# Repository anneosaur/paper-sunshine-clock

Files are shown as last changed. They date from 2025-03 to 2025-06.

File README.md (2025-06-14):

# paper sunshine clock


This project is a clock that tells time in a unique way. The face of the display looks like the sun with 12 rays representing 12 o’clock to 11 o’clock, going clockwise, which turn from black to yellow as the day progresses. Each ray is divided up into half hour segments, so the clock is able to tell you the current half hour. For example in the photo above, the clock is reading between 9 o’clock and 9:30. The display is made out of paper and uses thermochromic paint that changes color with heat. There is a thin circuit board behind the paper which provides the warmth to activate the thermochromic paint, changing the color of the rays. The clock also has Sparkle Mode, which will turn on a random ray every 10 seconds. It provides an entertaining show as the rays turn on and fade away (see [Videos](#Videos) below). The enclosure is 3D printed.

https://github.com/user-attachments/assets/e0f1c668-d030-4747-b99e-f9c4dc16aae8

---
### Reading the clock
The clock has 12 rays, representing 12 hours from 12 o'clock to 11 o'clock. Each ray is divided up into half hour segments. As each half hour of the day passes, the corresponding segment will turn from black to yellow. The clock face is fully yellow between 11:30-11:59. At 12:00, it'll reset. 

face_diagram

---
### How it works
The clock works by using thermochromic paint screen printed onto a piece of Japanese awagami paper. Behind that, is a flex PCB with large resistors mounted on the back. These resistors can be selectively turned on, warming up the paper and activating the thermochromic paint. 
Each ray on the PCB is a copper pour used to spread and hold heat from the resistors. It was designed using Python and an SVG drawing library, and converted into a KiCad footprint.

display_front_sm
display_back_sm

The control board is driven by an Atmega328PB and uses a DS3231MZ RTC for accurate time keeping. A coin cell battery is used to keep track of time even when the clock is unpowered. The time is initially set when programming the clock, and can be changed in +/- 30 minute increments using the two buttons on the back.

control_pcb_sm

It uses a multiplexing system which allows the 24 segments to be controlled with 10 connections. The rays of the clock are divided in 3 groups, with 4 rays each. Each group has a top and bottom ground connection connecting the rays (allowing the half hour segments to be individually controlled). The “similar” rays of each group (e.g., the first ray of each group, the second ray of each group, etc) have a shared 5v connection. So for example, to turn on the segment representing the first half hour of 12 o’clock, ground the bottom connection of the first group and apply 5v to the first ray.

display_schematic

For safety (since we’re applying heat to paper here), I used an eFuse to clamp the input voltage at 5v. There are also SMD fuses to prevent against excessive current going through the segments. 

In order to keep the rays at the proper temperature to activate the thermochromic paint (ideally around 90-95 F / 32-35 C), a temperature sensor reads the ambient temperature and will PWM the display to maintain a reasonably consistent temperature. This actually got a bit complicated, since the heat from the display would warm up the back compartment where the control PCB is and influence the temperature sensor. Fortunately, the temperature increases were fairly predicable and could be compensated for. From testing, the clock works well in room temperatures between 65-80 F / 18-27 C.

back_sm
front_side_sm
side_sm

# Videos

[Startup sequence](https://www.youtube.com/watch?v=sf5E_oBU3c0)

[5 minutes of Sparkle Mode in real time](https://www.youtube.com/watch?v=p_eX9BhE4EM)

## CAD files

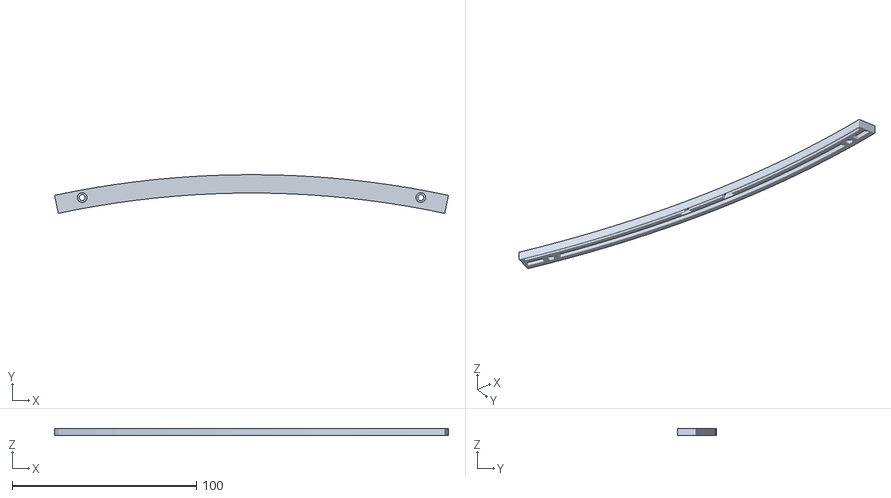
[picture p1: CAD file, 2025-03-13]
enclosure/stls/clock_enclosure_top.stl
214.1 x 21.0 x 4.00

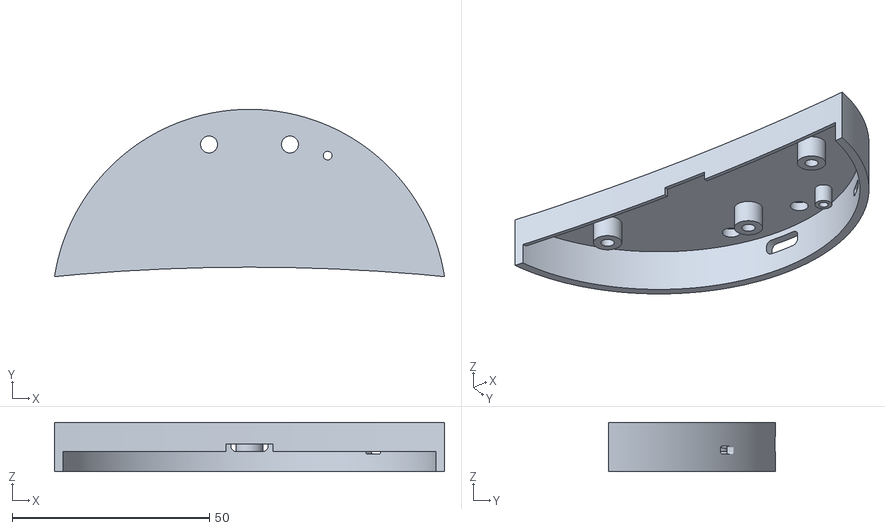
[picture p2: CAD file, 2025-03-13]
enclosure/stls/back_case.stl
98.8 x 42.4 x 12.5

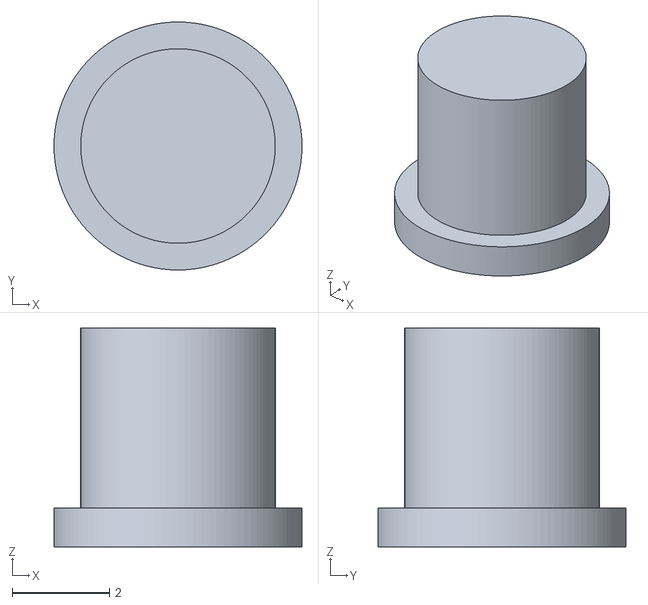
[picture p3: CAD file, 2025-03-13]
enclosure/stls/button.stl
5.10 x 5.10 x 4.50

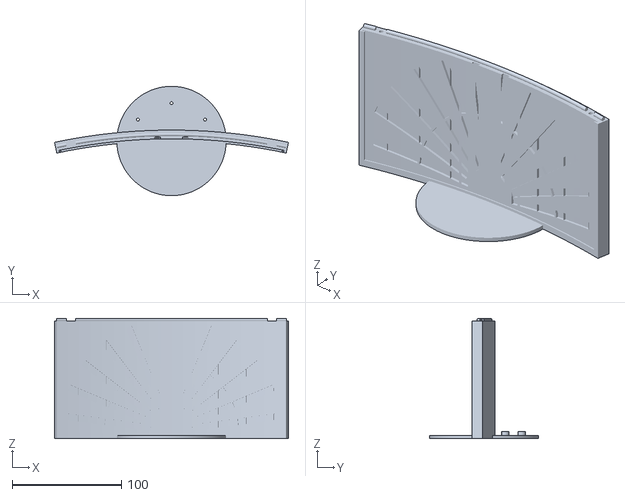
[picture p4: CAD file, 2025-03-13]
enclosure/stls/clock_enclosure.stl
214.1 x 100.0 x 110.2

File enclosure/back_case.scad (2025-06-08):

use <dotSCAD/rounded_square.scad>
include <common.scad>

$fn = 128;

button_diam = 4.2;
button_x = 20.5 / 2;
button_y = pcb_radius - 6.5;
button_thickness = 1;

light_pipe_outer_diam = 4;
light_pipe_inner_diam = 2.1;
light_pipe_coord_x = 19.8;
light_pipe_coord_y = 27.88 + 10.4;
led_height = 1;

module Pcb() {
  translate([0, 0, inner_height - top_standoff_height - pcb_thickness])
    linear_extrude(pcb_thickness)
      difference() {
        circle(pcb_radius);
        translate([0, -main_radius, 0])
        circle(main_radius + thickness + pcb_reduction);
        ScrewHoles(screw_outer_diam);
      }
}

module Inner() {
  difference() {
    linear_extrude(inner_height)
    circle(inner_radius);

    translate([0, 0, inner_height -top_standoff_height ])
    linear_extrude(top_standoff_height)
    translate([0, -main_radius, 0])
    circle(main_radius + thickness + 1);
  }
}

module Outer() {
  linear_extrude(outer_height)
    difference() {
      circle(d = base_diam);
      translate([0, -main_radius, 0])
        circle(main_radius + thickness);
    }
}

module UpperSandoffs() {
  difference() {
  translate([0, 0, inner_height - top_standoff_height])
    linear_extrude(top_standoff_height)
      ScrewHoles(standoff_diam);

  translate([0, 0, inner_height - top_standoff_height])
    linear_extrude(screw_insert_height)
      ScrewHoles(standoff_hole_diam);
  }
}

module LightPipe() {
  difference() {
    translate([light_pipe_coord_x, light_pipe_coord_y, inner_height - top_standoff_height + led_height])
      linear_extrude(top_standoff_height - led_height)
        circle(d=light_pipe_outer_diam);

    translate([light_pipe_coord_x, light_pipe_coord_y, inner_height - top_standoff_height + led_height])
      linear_extrude(top_standoff_height - led_height)
        circle(d=light_pipe_inner_diam);
  }
}

module LightPipeCutout() {
  translate([light_pipe_coord_x, light_pipe_coord_y, 0])
    linear_extrude(outer_height)
      circle(d=light_pipe_inner_diam);
}

module BackCover() {
  difference() {
    Outer();
    Inner();
    CableCutout();
    ButtonCutout();
    UsbCutout();
    LightPipeCutout();
    TempSensorCutout();
  }
  UpperSandoffs();
  LightPipe();
}

module CableCutout() {
  length = 12;
  height = 2;
  translate([-length / 2, 5, inner_height - top_standoff_height])
    cube([length, 10, height]);
}

module ButtonCutout() {
  translate([button_x, button_y, 0])
    linear_extrude(outer_height + 1)
      circle(d = button_diam);

  translate([-button_x, button_y, 0])
    linear_extrude(outer_height + 1)
      circle(d = button_diam);
}

module ButtonStandoff() {
  translate([button_x, button_y, 0])
    linear_extrude(outer_height + 2)
      circle(d = button_diam);

  translate([-button_x, button_y, 0])
    linear_extrude(outer_height + 2)
      circle(d = button_diam);
}

module UsbCutout() {
  usb_w = 3.78;
  usb_h = 9.44;
  translate([0, 52, -usb_w / 2 + inner_height - top_standoff_height + usb_w])
    rotate([90, 0, 0])
      linear_extrude(5)
        rounded_square([usb_h, usb_w], corner_r = 1.5, center = true);
}

module TempSensorCutout() {
  translate([adjacent(49, 45), opposite(49, 45), inner_height - top_standoff_height + pcb_thickness])
  rotate([-49, 90, 0])
  linear_extrude(5)
  rounded_square([2, 5], corner_r=0.5, center=true);
}

//Pcb();
BackCover();

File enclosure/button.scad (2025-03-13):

$fn = 100;

linear_extrude(0.8)
circle(d=5.1);

linear_extrude(4.5)
circle(d=4);

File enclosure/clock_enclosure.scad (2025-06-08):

use <dotSCAD/arc.scad>
use <dotSCAD/util/radians.scad>
use <dotSCAD/util/degrees.scad>
include <common.scad>

use <dotSCAD/bend.scad>

$fn = 128;


// Enclosure
enclosure_display = "W"; // [F:Full, T:Top Only, W:Without top]

module Base() {
  difference() {
    linear_extrude(bottom)
      circle(d = base_diam);
  }
}

module BaseStandoffs() {
  difference() {
    translate([0, 0, bottom])
      linear_extrude(bottom_standoff_height)
        ScrewHoles(standoff_diam);

    BottomScrewHoles();
  }
}

module BottomScrewHoles() {
  linear_extrude(10)
    ScrewHoles(screw_outer_diam);

  linear_extrude(screw_head_height)
    ScrewHoles(screw_head_diam);
}

module Body() {
  linear_extrude(total_height)
    arc(
      radius = main_radius,
      angle = [90 - angle / 2, 90 + angle / 2],
      width = thickness,
      width_mode = "LINE_OUTWARD"
    );
}

module CableCutOut() {
  coutout_height = 5;
  coutout_width = 12;

  translate([-coutout_width / 2, -thickness, bottom])
    cube([coutout_width, thickness*2, coutout_height]);
}

module FrontCutout() {
  translate([0, 0, bottom + margin/2])
    linear_extrude(paper_visable_h)
      arc(
        radius = main_radius,
        angle = [90 - front_cutout_angle / 2, 90 + front_cutout_angle / 2],
        width = paper_setback,
        width_mode = "LINE_OUTWARD"
      );
}

module Paper() {
  translate([0, 0, bottom])
    linear_extrude(paper_h)
      arc(
        radius = paper_radius,
        angle = [90 - paper_angle / 2, 90 + paper_angle / 2],
        width = paper_thickness,
        width_mode = "LINE_OUTWARD"
      );
}

module ResistorCutout() {
    translate([0, -206/radians(angle) +resistor_thickness+paper_setback + paper_thickness, 3])
    rotate([0, 0, 90 - angle/2])
    bend(size = [206, 106, resistor_thickness], angle = angle)
    linear_extrude(2)
    import("clock_face.svg");
}

module ScrewInserts(diam, height, z) {
  translate([0, thickness / 2 + paper_setback, z])
    rotate([0, 0, 10.5])
      translate([0, main_radius, 0])
        linear_extrude(height)
          circle(d = diam);

  translate([0, thickness / 2 + paper_setback, z])
    rotate([0, 0, -10.5])
      translate([0, main_radius, 0])
        linear_extrude(height)
          circle(d = diam);
}

module TopRetainingClip(diam){
    translate([0, -main_radius+ thickness / 2 + paper_setback, total_height-margin+1.2])
    rotate([0, 0, (90 - 20/2)])
    rotate_extrude(angle=20) translate([main_radius,0,0]) circle(d=diam);

    translate([0, -main_radius+ thickness / 2 + paper_setback, total_height-margin+1.2])
    rotate([0, 0, 78]) // 78
    rotate_extrude(angle=1) translate([main_radius,0,0]) circle(d=diam); // 1

    translate([0, -main_radius+ thickness / 2 + paper_setback, total_height-margin+1.2])
    rotate([0, 0, 102]) // 102
    rotate_extrude(angle=-1) translate([main_radius,0,0]) circle(d=diam); // -1
}

module Enclosure() {
    difference() {
      union() {
        translate([0, -main_radius, 0])
          Body();
        Base();
      }
      CableCutOut();

      translate([0, -main_radius, 0])
      union() {
        ScrewInserts(standoff_hole_diam, margin + 4, total_height -margin - 4);
        ScrewInserts(screw_head_diam, screw_head_height, total_height - 1);
      }

      translate([0, -main_radius, 0])
      union() {
        Paper();
        FrontCutout();
      }

      ResistorCutout();
      BottomScrewHoles();
    }

  BaseStandoffs();
}

module EnclosureWithoutTop() {
  cube_w = paper_w + margin * 2;

  difference() {
    Enclosure();
    translate([-cube_w/2, -base_diam / 2, total_height - margin])
      cube([cube_w, base_diam, margin]);
  }
  TopRetainingClip(3);
}

module EnclosureTop() {
  cube_w = paper_w + margin * 2;
  cube_d = base_diam;
  cube_z = total_height - margin;
  difference() {
    Enclosure();
    TopRetainingClip(3.4);

    translate([-cube_w/2, -cube_d/2, 0])
    cube([cube_w, cube_d, cube_z]);  
  }
}

if (enclosure_display == "F") Enclosure();
if (enclosure_display == "T") EnclosureTop();
if (enclosure_display == "W") EnclosureWithoutTop();

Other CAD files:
enclosure/common.scad

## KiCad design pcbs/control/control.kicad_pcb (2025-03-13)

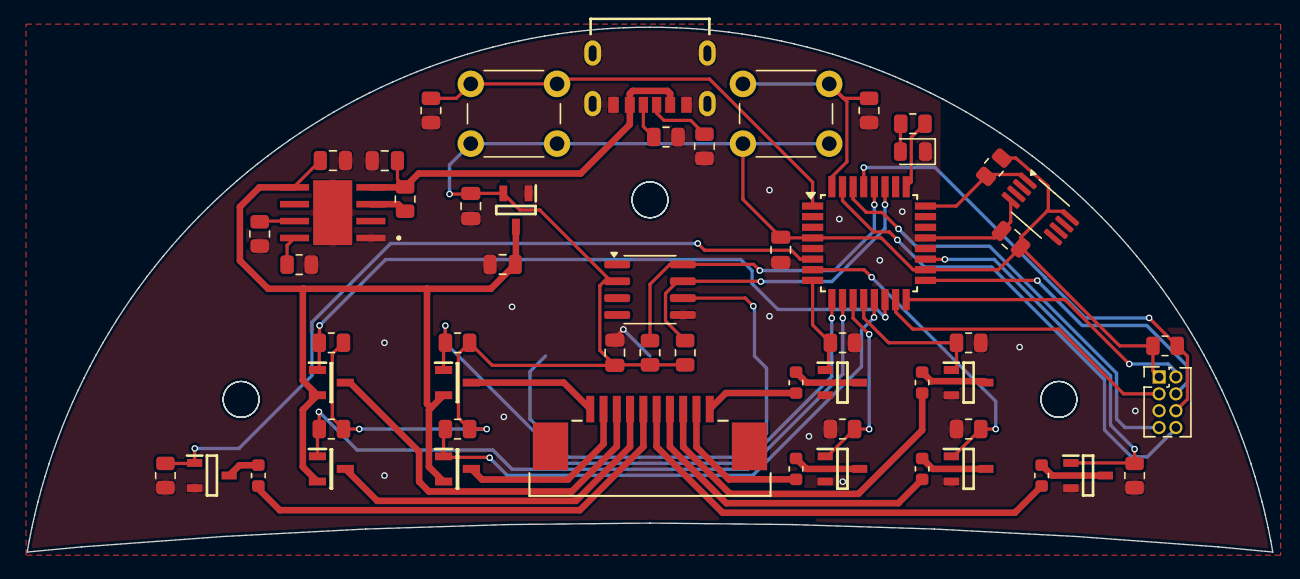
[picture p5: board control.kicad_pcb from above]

Board: 2 copper layers, 93.8 x 39.5 mm, 58 parts (1 on the bottom side), 49 nets.

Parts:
BT1: 3000TR; BAT_3000TR
C1, C6: 1uF; C_0805_2012Metric
C2, C3, C4, C8: 0.1uF; C_0805_2012Metric
C5: 2.2uF; C_0805_2012Metric
D1: LED; LED_0805_2012Metric
D5: AP2210N-3.3TRG1; SOT95P282X145-3N
F1, F2, F3, F4, F5, F6: Fuse; Fuse_0603_1608Metric
J2: USB4125-GF-A-0190; GCT_USB4125-GF-A-0190_REVA2
J3: Conn_01x10_Pin; CON10_SMT-RA_FCC-FPC2
J4: Conn_02x04_Odd_Even; PinHeader_2x04_P1.27mm_Vertical
Q1, Q2, Q3, Q4: SI2393DS-T1-GE3; SOT95P237X112-3N
Q5, Q6, Q7, Q8, Q9, Q10: DMN2020LSN-7; SOT95P285X130-3N
R1, R2, R3, R4, R5, R6, R7, R8, R9, R10, R13, R14, R17: 10k; R_0805_2012Metric
R11, R12, R20: 4.7k; R_0805_2012Metric
R15, R16: 5.1k; R_0805_2012Metric
R18: 60; R_0805_2012Metric
R19: 500; R_0805_2012Metric
R21, R22: 400k; R_0805_2012Metric
Ref**: Val**; control_pcb_outline
SW1: Sparkle; SW_PUSH_6mm
SW2: Time Adj; SW_PUSH_6mm
U1: DS18B20U; MSOP-8_3x3mm_P0.65mm
U2: DS3231MZ; SOIC-8_3.9x4.9mm_P1.27mm
U3: TPS259621DDAT; IC_TPS259621DDAT
U6: ATmega328PB-A; TQFP-32_7x7mm_P0.8mm

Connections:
/3.3v: C2.2, C3.2, C5.2, C8.2, D5.2 (VOUT), J4.1, R1.1, R2.1, R3.1, R4.1, R11.1, R12.1, R17.1, R20.1, SW1.1, SW2.1, U1.8 (V_{DD}), U2.2 (VCC), U6.4 (VCC), U6.18 (AVCC)
/5v: C1.2, C6.2, D5.3 (VIN), Q1.2 (S), Q2.2 (S), Q3.2 (S), Q4.2 (S), U3.5 (OUT)
/ADC1: R20.2, U1.1 (DQ), U6.24 (PC1)
/ADC2: R18.2, U6.25 (PC2)
/ADC6: Q10.1 (G), R10.2, U6.19 (PE2)
/G1B: F2.2, J3.6
/G1T: F1.2, J3.5
/G2B: F4.2, J3.8
/G2T: F3.2, J3.7
/G3B: F5.2, J3.9
/G3T: F6.2, J3.10
/MISO: J4.2, U6.16 (PB4)
/MOSI: J4.3, U6.15 (PB3)
/PIN 2: R13.2, SW2.2, U6.32 (PD2)
/PIN 3: R14.2, SW1.2, U6.1 (PD3)
/PIN 5: Q1.1 (G), R1.2, U6.9 (PD5)
/PIN 6: Q4.1 (G), R4.2, U6.10 (PD6)
/PIN 7: Q7.1 (G), R7.2, U6.11 (PD7)
/PIN 8: Q8.1 (G), R8.2, U6.12 (PB0)
/PIN 9: Q2.1 (G), R2.2, U6.13 (PB1)
/PIN 10: Q3.1 (G), R3.2, U6.14 (PB2)
/PIN 20: Q9.1 (G), R9.2, U6.7 (XTAL1/PB6)
/PIN 21: Q6.1 (G), R6.2, U6.8 (XTAL2/PB7)
/PIN 24: Q5.1 (G), R5.2, U6.6 (PE1)
/RESET: J4.6, R17.2, U6.29 (~RESET/PC6)
/RTC_BAT: BT1.P1, BT1.P2, U2.6 (VBAT)
/RX: J4.7, U6.30 (PD0)
/SCK: J4.4, U6.17 (PB5)
/SCL: R11.2, U2.8 (SCL), U6.28 (PC5)
/SDA: R12.2, U2.7 (SDA), U6.27 (PC4)
/TX: J4.8, U6.31 (PD1)
/V1: J3.1, Q1.3 (D)
/V2: J3.2, Q2.3 (D)
/V3: J3.3, Q3.3 (D)
/V4: J3.4, Q4.3 (D)
/VBUS: C4.2, J2.A9 (VBUS_1), J2.B9 (VBUS_2), R22.1, U3.4 (IN)
GNDD: BT1.N, C1.1, C2.1, C3.1, C4.1, C5.1, C6.1, C8.1, D1.1 (K), D5.1 (GND), J2.A12 (GND_1), J2.B12 (GND_2), J2.S1, J2.S2, J2.S3, J2.S4, J4.5, Q5.2 (S), Q6.2 (S), Q7.2 (S), Q8.2 (S), Q9.2 (S), Q10.2 (S), R5.1, R6.1, R7.1, R8.1, R9.1, R10.1, R13.1, R14.1, R15.1, R16.1, R19.1, R21.2, U1.4 (GND), U2.5 (GND), U3.1 (GND), U3.9 (EXP), U6.5 (GND), U6.21 (GND)
unnamed: D1.2 (A), R18.1
unnamed: J2.A5 (CC1), R15.2
unnamed: J2.B5 (CC2), R16.2
unnamed: F1.1, Q5.3 (D)
unnamed: F6.1, Q6.3 (D)
unnamed: F5.1, Q7.3 (D)
unnamed: F4.1, Q8.3 (D)
unnamed: F3.1, Q9.3 (D)
unnamed: F2.1, Q10.3 (D)
unnamed: R22.2, U3.3 (EN/UVLO)
unnamed: R19.2, U3.7 (ILM)
unnamed: R21.1, U3.8 (OVCSEL)

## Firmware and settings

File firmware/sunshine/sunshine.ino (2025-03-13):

#include <DS3231.h>
#include <DS18B20.h>
#include <avr/wdt.h>

#define VA 5
#define VB 9
#define VC 10
#define VD 6

#define GB1 A6
#define GT1 24

#define GB2 8
#define GT2 20

#define GB3 7
#define GT3 21

#define LED A2

#define TIME_ADJ_BTN 3
#define MODE_ADJ_BTN 2

#define DELAY 1000

#define SPARKLE_RECENT_COUNT 20

#define MODE_CLOCK 0
#define MODE_SPARKLE 1
#define MODE_TIME_SET 2
#define MODE_TIME_RESET 3

DS3231 myRTC;
DS18B20 ds(A1);

int voltageSupply[4] = { VA, VB, VC, VD };

int ground[3][2] = {
  { GB1, GT1 },
  { GB2, GT2 },
  { GB3, GT3 },
};

bool h12Flag;
bool pmFlag;

int lastSegment;

volatile int mode = MODE_CLOCK;
volatile bool modeSwitch = false;

volatile bool incrementTimeTriggered = false;
volatile bool decrementTimeTriggered = false;
unsigned long lastTimeSetTouch = 0;

unsigned long lastTimeResetTouch = 0;
volatile bool timeResetTriggered = false;
int timeResetBtnCount = 0;

unsigned long lastTempUpdate = 0;
float lastTemp;


int sparkleRecent[SPARKLE_RECENT_COUNT] = {};

void setup() {

  wdt_enable(WDTO_8S);
  Wire.begin();

  pinMode(LED, OUTPUT);

  pinMode(VA, OUTPUT);
  pinMode(VB, OUTPUT);
  pinMode(VC, OUTPUT);
  pinMode(VD, OUTPUT);

  pinMode(GB1, OUTPUT);
  pinMode(GT1, OUTPUT);

  pinMode(GB2, OUTPUT);
  pinMode(GT2, OUTPUT);

  pinMode(GB3, OUTPUT);
  pinMode(GT3, OUTPUT);

  pinMode(TIME_ADJ_BTN, INPUT);
  pinMode(MODE_ADJ_BTN, INPUT);

  reset();

  myRTC.setClockMode(true);

  attachInterrupt(digitalPinToInterrupt(TIME_ADJ_BTN), interruptTimeSetMode, RISING);
  attachInterrupt(digitalPinToInterrupt(MODE_ADJ_BTN), interruptSparkleMode, RISING);

  ds.selectNext();

  lastSegment = getSegment();

  digitalWrite(LED, HIGH);
  clockStartup();
  digitalWrite(LED, LOW);
}

void interruptSparkleMode() {
  static unsigned long last_interrupt_time = 0;
  unsigned long interrupt_time = millis();

  if (interrupt_time - last_interrupt_time > 500) {
    if (mode == MODE_CLOCK) {
      mode = MODE_SPARKLE;
      digitalWrite(LED, HIGH);
    } else if (mode == MODE_SPARKLE) {
      mode = MODE_CLOCK;
      modeSwitch = true;
      digitalWrite(LED, LOW);
    } else if (mode == MODE_TIME_SET) {
      incrementTimeTriggered = true;
      lastTimeSetTouch = millis();
    }
  }
  last_interrupt_time = interrupt_time;
}

void interruptTimeSetMode() {
  static unsigned long last_interrupt_time = 0;
  unsigned long interrupt_time = millis();

  if (interrupt_time - last_interrupt_time > 500) {
    if (mode == MODE_CLOCK) {
      digitalWrite(LED, HIGH);
      mode = MODE_TIME_SET;
      modeSwitch = true;
    } else if (mode == MODE_TIME_SET) {
      decrementTimeTriggered = true;
    } else if (mode == MODE_SPARKLE) {
      mode = MODE_TIME_RESET;
      timeResetTriggered = true;
      modeSwitch = true;
    } else if (mode == MODE_TIME_RESET) {
      timeResetTriggered = true;
    }
  }
  last_interrupt_time = interrupt_time;
}

void clockSequence(int holdDelay, int segment, int pwm, bool returnEarly = false) {
  for (int i = 0; i < 4; i++) {
    for (int s = 0; s <= segment; s++) {
      if (int(floor((s % 8) / 2)) == i) {
        turnOn(s, pwm);
        if (returnEarly && segment == s) {
          _delay(holdDelay);
          reset();
          return;
        };
      }
    }
    _delay(holdDelay);
    reset();
  }
}

void clockStartup() {
  int segment = getSegment();
  int startupDelay = getStartupDelay();
  int stopSegment;
  bool returnEarly = false;

  stopSegment = (segment < 7) ? segment : 7;
  if (stopSegment <= 7) returnEarly = true;
  clockSequence(startupDelay, stopSegment, 0, returnEarly);

  if (segment > 7) {
    stopSegment = (segment < 15) ? segment : 15;
    if (stopSegment <= 15) returnEarly = true;
    clockSequence(startupDelay, stopSegment, 0, returnEarly);
  }

  if (segment > 15) {
    stopSegment = (segment < 23) ? segment : 23;
    if (stopSegment <= 23) returnEarly = true;
    clockSequence(startupDelay, stopSegment, 0, returnEarly);
  }
}

void sparkleAddToRecent(int s) {
  for (int i = 0; i < SPARKLE_RECENT_COUNT - 1; i++) {
    sparkleRecent[i] = sparkleRecent[i + 1];
  }
  sparkleRecent[SPARKLE_RECENT_COUNT - 1] = s;
}

int getPwm() {
  float temp = getAdjustedTemp();
  int pwm = (8 * temp) - 445;
  return pwm;
}

int getStartupDelay() {
  float temp = getTemp();
  int startupDelay = (((-0.42 * temp) + 37) * 1000) + 2000;
  startupDelay = startupDelay > 10000 ? 10000 : startupDelay;
  return startupDelay;
}

int getSegment() {
  float hour = float(myRTC.getHour(h12Flag, pmFlag));
  int minute = myRTC.getMinute();

  if (hour == 12) hour = 0;
  if (minute >= 30) hour += 0.5;
  int segment = int(hour * 2);
  return segment;
}

float getAdjustedTemp() {
  float boardTemperatureF = getTemp();
  float offset = (0.3 * lastSegment / 2) + 2;
  float adjustedTemp = boardTemperatureF - offset;

  return adjustedTemp;
}

float getTemp() {
  if (lastTempUpdate == 0 || millis() - lastTempUpdate > 60000) {
    float boardTemperatureF = ds.getTempF();
    if (boardTemperatureF < 60) boardTemperatureF = 60;

    lastTempUpdate = millis();
    lastTemp = boardTemperatureF;
    return boardTemperatureF;
  }
  return lastTemp;
}

void incrementTime() {
  int currentHour = myRTC.getHour(h12Flag, pmFlag);
  if (currentHour == 12) currentHour = 0;
  int newHour = currentHour;
  int currentMinute = myRTC.getMinute();

  int newMinute = currentMinute + 30;
  if (newMinute >= 60) {
    newMinute -= 60;
    newHour += 1;
    if (newHour == 12) newHour = 0;
  }

  myRTC.setHour(newHour);
  myRTC.setMinute(newMinute);

  incrementTimeTriggered = false;
}

void decrementTime() {
  int currentHour = myRTC.getHour(h12Flag, pmFlag);
  if (currentHour == 12) currentHour = 0;
  int newHour = currentHour;
  int currentMinute = myRTC.getMinute();

  int newMinute = currentMinute - 30;
  if (newMinute <= 0) {
    newMinute += 60;
    newHour -= 1;
    if (newHour < 0) newHour = 11;
  }

  myRTC.setHour(newHour);
  myRTC.setMinute(newMinute);

  decrementTimeTriggered = false;
}

bool sparkleIsRecent(int s) {
  for (int i = 0; i < SPARKLE_RECENT_COUNT; i++) {
    if (sparkleRecent[i] == s) return true;
  };

  return false;
}

void reset() {
  digitalWrite(GB1, LOW);
  digitalWrite(GT1, LOW);

  digitalWrite(GB2, LOW);
  digitalWrite(GT2, LOW);

  digitalWrite(GB3, LOW);
  digitalWrite(GT3, LOW);

  digitalWrite(VA, HIGH);
  digitalWrite(VB, HIGH);
  digitalWrite(VC, HIGH);
  digitalWrite(VD, HIGH);
}

void turnOn(int num, int pwm) {
  if (num < 0 || num > 23) reset();

  int h = voltageSupply[int(floor((num % 8) / 2))];

  int group = int(floor(num / 8));
  int g = ground[group][num % 2];

  analogWrite(h, pwm);
  digitalWrite(g, HIGH);
}

void _delay(int delayCount) {
  for (int c = 0; c < delayCount; c += 100) {
    if (incrementTimeTriggered || decrementTimeTriggered || modeSwitch) return;
    delay(100);
    wdt_reset();
  }
}

// Modes
void modeClock() {
  int segment = getSegment();

  if ((segment == 0 && lastSegment >= 1) || segment > lastSegment) {
    reset();
    turnOn(segment, 0);
    lastSegment = segment;

    int additionalDelay = 0;
    if (segment % 2 == 1) additionalDelay = 3000;
    _delay(getStartupDelay() + additionalDelay);
    reset();

    if (mode == MODE_CLOCK) {
      digitalWrite(LED, HIGH);
      clockSequence(2000, segment - 1, 0);
      digitalWrite(LED, LOW);
    }

  } else if (segment < lastSegment) {
    lastSegment = segment;
  }

  int pwm = getPwm();

  clockSequence(DELAY, segment, pwm);
}

void modeSparkle() {
  int segment = rand() % (23 + 1);
  if (sparkleIsRecent(segment)) return;

  turnOn(segment, 0);
  sparkleAddToRecent(segment);

  if (segment % 2 == 1) {
    turnOn(segment - 1, 0);
    sparkleAddToRecent(segment - 1);
  };

  int sparkleDelay = getStartupDelay() - 3000;
  _delay(sparkleDelay);
  reset();

  _delay(10000 - sparkleDelay);
}

void timeSetBlink() {
  digitalWrite(LED, LOW);
  delay(250);
  digitalWrite(LED, HIGH);
  delay(250);
  digitalWrite(LED, LOW);
  delay(250);
  digitalWrite(LED, HIGH);
}

void modeTimeSet() {
  if (lastTimeSetTouch == 0) {
    lastTimeSetTouch = millis();
  }
  if (millis() - lastTimeSetTouch > 5000) {
    digitalWrite(LED, LOW);
    lastTimeSetTouch = 0;
    mode = MODE_CLOCK;
  }

  if (incrementTimeTriggered) {
    incrementTime();
    lastTimeSetTouch = millis();
    timeSetBlink();
  } else if (decrementTimeTriggered) {
    decrementTime();
    lastTimeSetTouch = millis();
    timeSetBlink();
  }

  modeClock();
}

void modeTimeReset() {
  if (lastTimeResetTouch == 0) {
    lastTimeResetTouch = millis();
  }

  if (millis() - lastTimeResetTouch > 5000) {
    digitalWrite(LED, LOW);
    lastTimeResetTouch = 0;
    timeResetTriggered = false;
    timeResetBtnCount = 0;
    mode = MODE_CLOCK;
  }

  if (timeResetTriggered) {
    if (timeResetBtnCount == 9) {
      timeResetBtnCount = 0;
      lastTimeResetTouch = 0;
      myRTC.setHour(0);
      myRTC.setMinute(0);
      myRTC.setSecond(0);
      mode = MODE_CLOCK;
      digitalWrite(LED, LOW);
    } else {
      timeResetBtnCount += 1;
      lastTimeResetTouch = millis();
      timeResetTriggered = false;
      timeSetBlink();
    }
  }
  wdt_reset();
  delay(25);
}

void loop() {
  if (mode == MODE_CLOCK) {
    if (modeSwitch) {
      modeSwitch = false;
      clockStartup();
    }
    modeClock();
  } else if (mode == MODE_SPARKLE) {
    modeSwitch = false;
    modeSparkle();
  } else if (mode == MODE_TIME_SET) {
    modeSwitch = false;
    modeTimeSet();
  } else if (mode == MODE_TIME_RESET) {
    modeSwitch = false;
    modeTimeReset();
  }
}

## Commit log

2025-03-13 added to version control
    [back_case.scad, back_case.stl, button.scad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]
2025-06-08 enclosure parameter improvement
    [back_case.scad, clock_enclosure.scad, common.scad]
